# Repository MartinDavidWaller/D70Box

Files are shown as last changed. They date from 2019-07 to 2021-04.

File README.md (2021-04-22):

# D70Box

The D70Box project is documented in Practical Wireless, October 2019. If you require further information,
such as the associated circuit diagram or a PCB, then please contact me at martin@the-wallers.net.

*The project seems to have been rather popular with over 50 PCBs being shipped and, I assume 50 units being built. 
I think the reason for this is all down to the project keeping the look and feel of the original D70. It was an 
iconic look and people seem to be very nostalgic about it.*

# Erratum

Fonts! I originally thought that the label font was "microgramma d bold extended" but having listened to
Kermode and Mayo's Film Review podcast recently I think it might be "eurostile bold extended"! References
to this font include:

- https://typesetinthefuture.com/
- https://www.wired.co.uk/article/sci-fi-font-eurostile-bold-extended

A small design fault has been noticed. On the 74LS00 quad NAND gate pins 1,2,3,4,5,6, and 7 are all 
connected to ground. Pins 3 and 6 should have been left unconnected. This will not impact the overall 
functionality of the device but may result in slightly more current drain.

The suggested fix, for those who have soldered the 74LS00 directly onto the board and for those using 
a DIL socket, is to simply snip off pins 3 and 6.

V1.4 of the PCB is now available that will fix the problem without the need to snip off pins.

Some of the Arduino Pro Micro devices seem to be identifying themselves as "LilyPad Arduino USB" devices. If
the one you have claims to be one of these then under Tools > Boards select the "LilyPad Arduino USB" device 
and not "Arduino Leonardo".

Some Arduino Pro Micro devices also seem to be "Leonardo ETH" devices. A symtom of having the wrong Leonardo 
device selected seems to be odd data being displayed on the attached Bluetooth device.

A problem has been reported building the code with the Arduino 1.5.6-r2 IDE. This manifests with an
error saying "SwitchStates does not name a type". If you are facing this issue then please contact
me at martin@the-wallers.net and I'll provide the fix.

A problem has been reported where random 'Z' and random '9' characters were not being generated
as expected. This has now been fixed. Version number changed to V1.1.

## Required Hardware

Do shop around for these devices on ebay. I've noticed that the prices associated with the links below
have risen. You should be aiming to pay around £4 - £5 for the Arduino Pro Micro, or less if you buy from
China, and £2 - £3 for the Bluetooth module.

The circuit is based around the Arduino Pro Micro. This was purchased via ebay
from the URL https://www.ebay.co.uk/itm/1-2-5-10PCS-Pro-Micro-ATmega32U4-16MHz-5V-Replace-Pro-Mini-ATmega328-For-Arduino/283052304952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 but
it must be noted that other vendors supply this device too! Other vendors, especially if you are willing to wait, sell these much cheaper!

The HC-05 Bluetooth module was also purchased via ebay from the URL https://www.ebay.co.uk/itm/HM-10-BLE-Bluetooth-4-0-CC2540-CC2541-Serial-Wireless-Module-Arduino-F/123600639430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 
but it must be noted that other vendors supply this device too! The device is advertised as the HM-10 but it should be fine.

Other components include:

Resistors

- R1 150
- R5 2K
- R6 1K

Variable Resistors

- R2 10K Lin
- R3 10K Lin
- R4 22K Lin (Switched)

Semicondictors

- Q1 BFY51 or 2N3019
- U2 74LS00

Miscellaneous

- U3 Switch SPDT centre off
- S1 3.5 mm switch mono socket
- S2 3.5 mm switch mono socket
- SP1 8 Ohm speaker
- Header pins as required

DIL sockets for U2
Header sockets for Arduino and Bluetooth adapter

## Installing the Build Software

Start by installing the Arduino IDE. This can be found at:

https://www.arduino.cc/en/Main/Software

For the purpose of this build the Windows version Arduino 1.8.8 was used. 
All default installation options were accepted.

## Compiling the source code

- Download the associated ZIP file and uncompress it on your drive
- Open the Arduino IDE and then open the D70Box.ino project file in the Source\D70Box folder
- Navigate to Tools > Boards and select "Arduino Leonardo" (See Erratum above)
- Click the "Verify" button (Round circle with a tick mark in it - top left), if successful you will see something like 
"Sketch uses 14522 bytes (50%) of program storage space. Maximum is 28672 bytes.
Global variables use 741 bytes (28%) of dynamic memory, leaving 1819 bytes for local variables. Maximum is 2560 bytes."
though the number may not be exact.
- Make sure that the Arduino is plugged into your PC. Navigate to Tools > Port and make sure that the correct port is selected. See USB Issues below.
- Click the "Upload" button (Right pointing arrow - top left) to up load the software.
- The device should now be programmed correctly.

## USB Issues

Some users have reported issues connecting the Arduino to the PC USB 3.0 sockets.
It seems that the Arduino Pro-Micro is happier connected to a USB 2.0 sockets for programming.
More information can be found here: https://learn.sparkfun.com/tutorials/pro-micro--fio-v3-hookup-guide/all

## PCB Revisions

- V1.4 - September 29th, 2019 - Fixed the issue with 7400 outputs pins 3 and 6 being tied low.
- V1.3 - June 4th, 2019 - Fixed legend for T1, should read BFY51 and not BFY71.
- V1.2 - May 24th, 2019 - Added BlueTooth support.
- V1.1 - ?
- V1.0 - April 5th, 2019 - Initial board design.

## Knobs

I have managed to re-create a realistic looking D70 knob. 
The knob is designed to provide a friction fit to a knurled 6mm diameter shaft - split or otherwise.
The 3D design has been created using
OpenSCAD - see https://www.openscad.org/ 

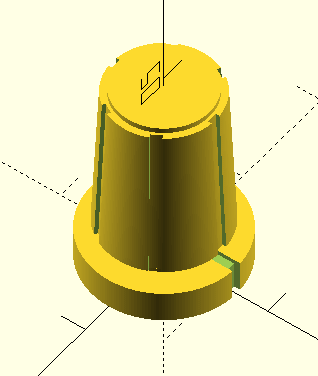
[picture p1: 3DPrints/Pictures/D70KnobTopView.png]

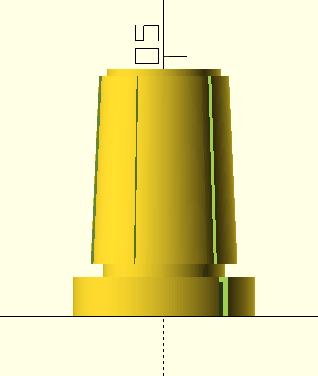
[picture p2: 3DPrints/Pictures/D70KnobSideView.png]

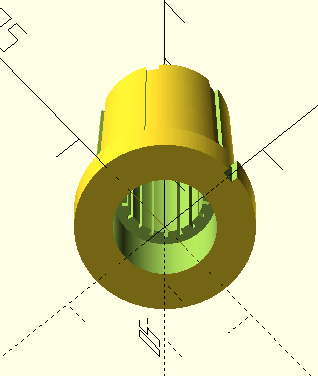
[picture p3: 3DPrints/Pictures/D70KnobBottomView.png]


The OpenSCAD source file and associated STL file can be found in the 3DPrints folder.

## Notes

The Delay and Speed setting may seem wrong relative to the knob position. The best way to check this is to use the BlueTooth
interface and look for the Delay and Speed setting. Adjust the two control until the values displayed match values on the
legend. Then adjust the knobs so that the indicator is as close as possible to the legend value. The attained proximity will 
depend on the potentiometer shaft type, smooth or knurled / serrated etc.

The BFY51 transistor can be substituted with a 2N3019. See https://ham.stackexchange.com/questions/8990/can-anyone-please-suggest-a-substitute-for-the-bfy51-transistor/9031

The Bluetooth card may prompt for a PIN, this is likely to be either 1234, or 0000.

## User Builds

David, G4DMP, has sent in a picture of his completed build.

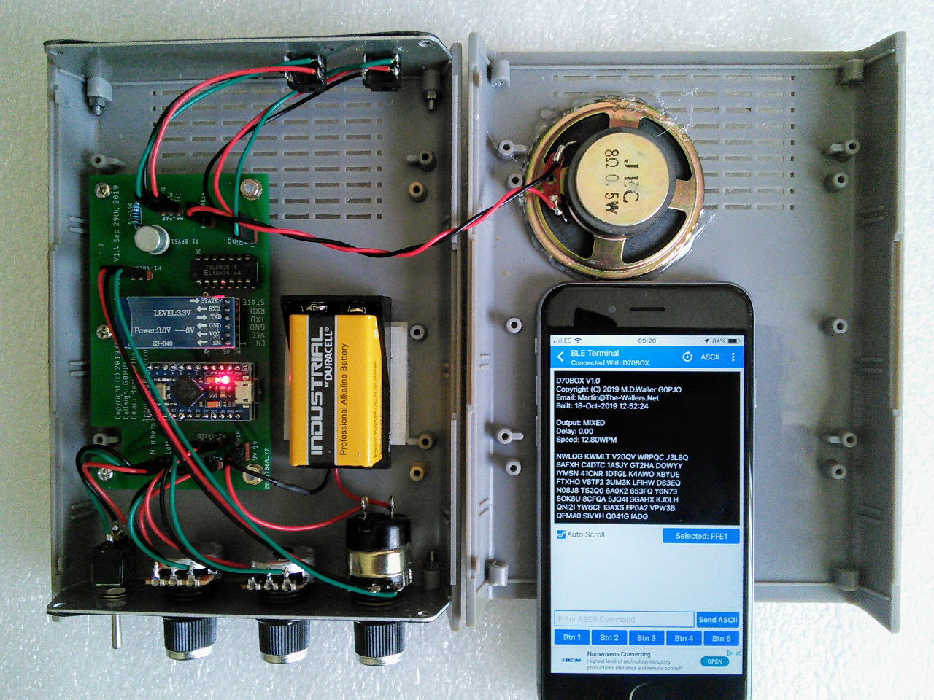
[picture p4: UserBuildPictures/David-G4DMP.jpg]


David, G4EDR, has also sent in a picture of his completed build.

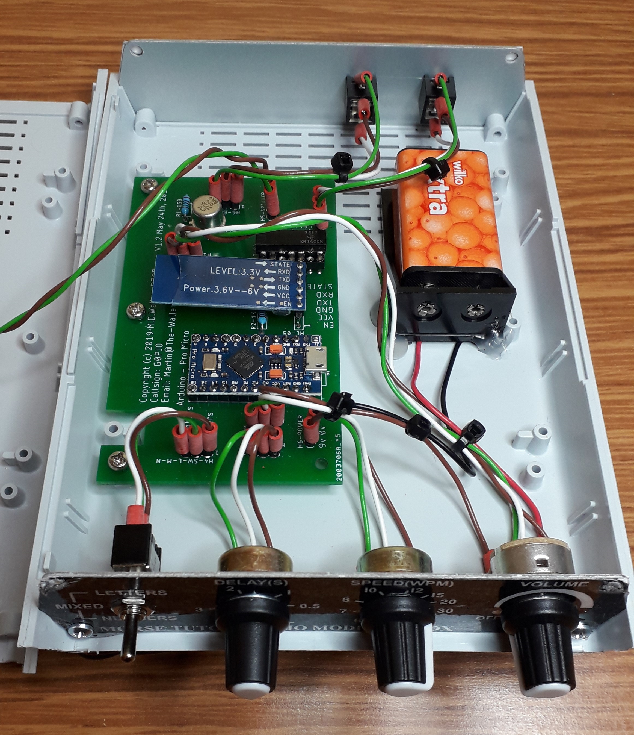
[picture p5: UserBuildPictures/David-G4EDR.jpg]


Stephen, GI7ISX, has also sent in a couple of pictures of his completed build.

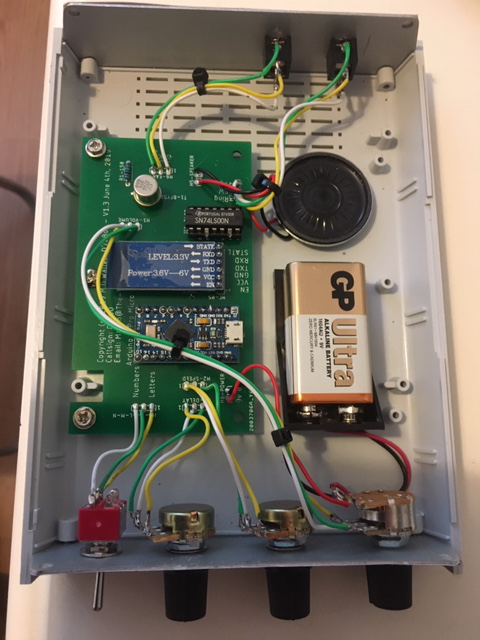
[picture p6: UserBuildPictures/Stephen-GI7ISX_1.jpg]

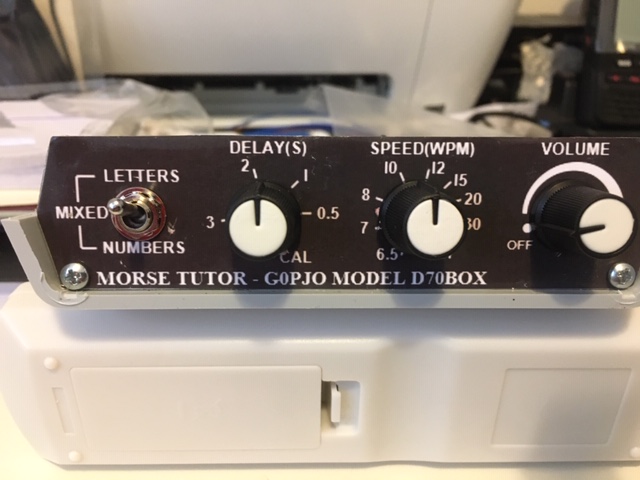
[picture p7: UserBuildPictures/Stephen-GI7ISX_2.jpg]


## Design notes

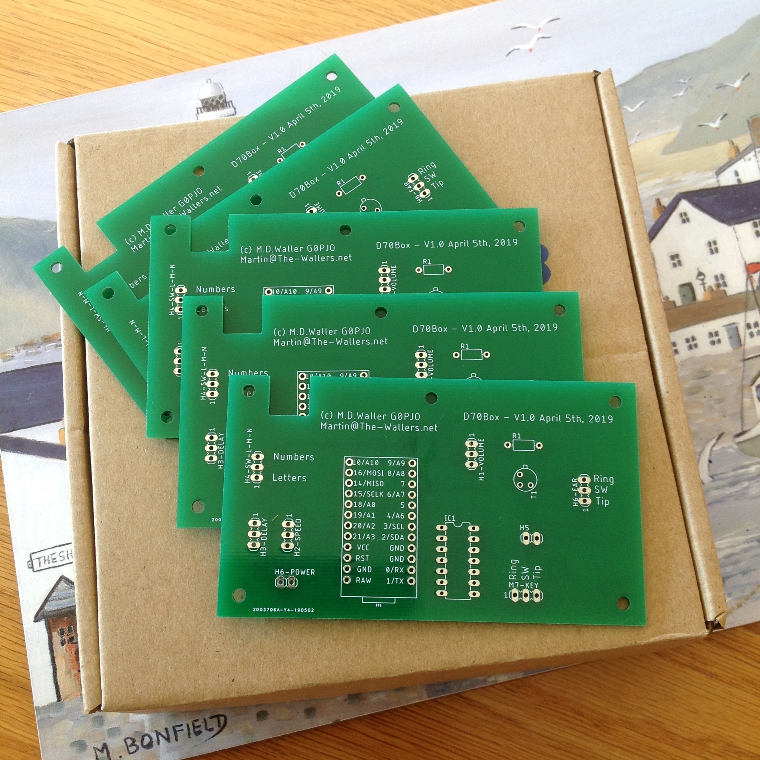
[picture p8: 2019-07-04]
Pictures/PCB_V1_0.JPG

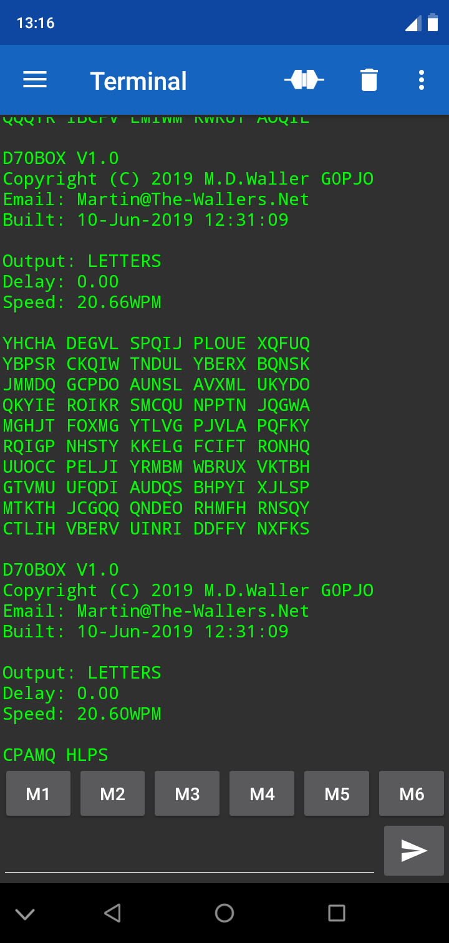
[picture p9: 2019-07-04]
Pictures/Screenshot_20190610-131609.png

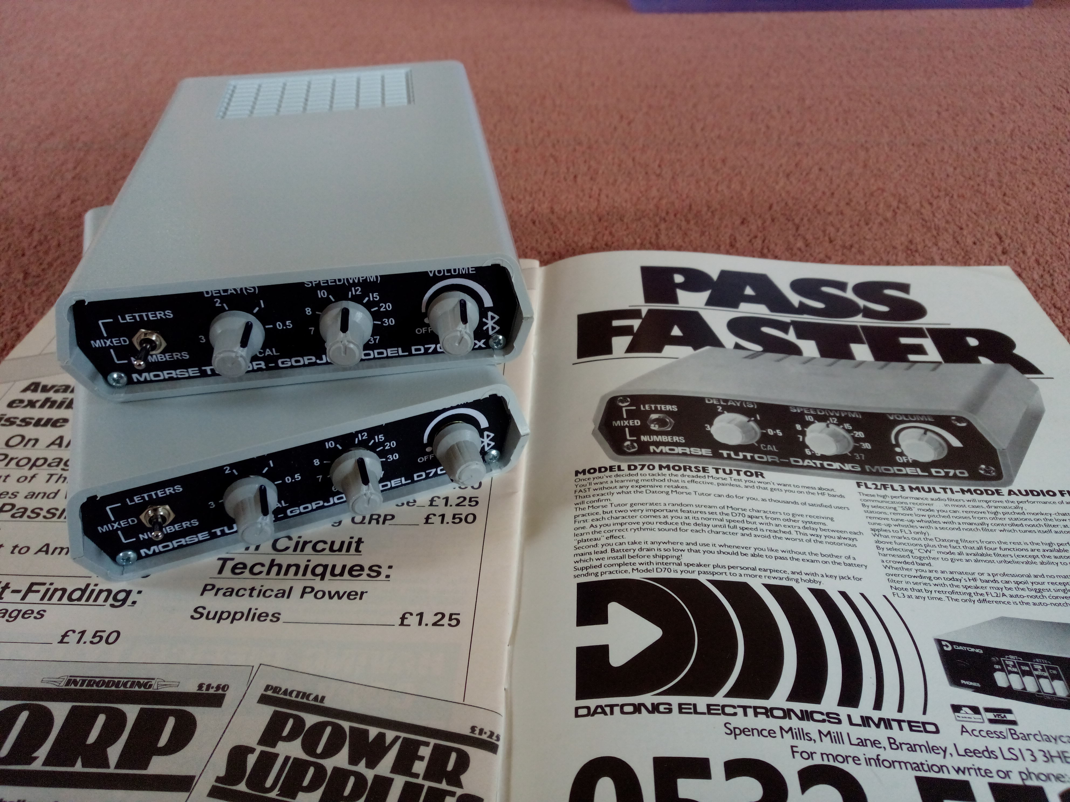
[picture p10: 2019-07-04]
Pictures/IMG_20190610_142815_1CS.jpg

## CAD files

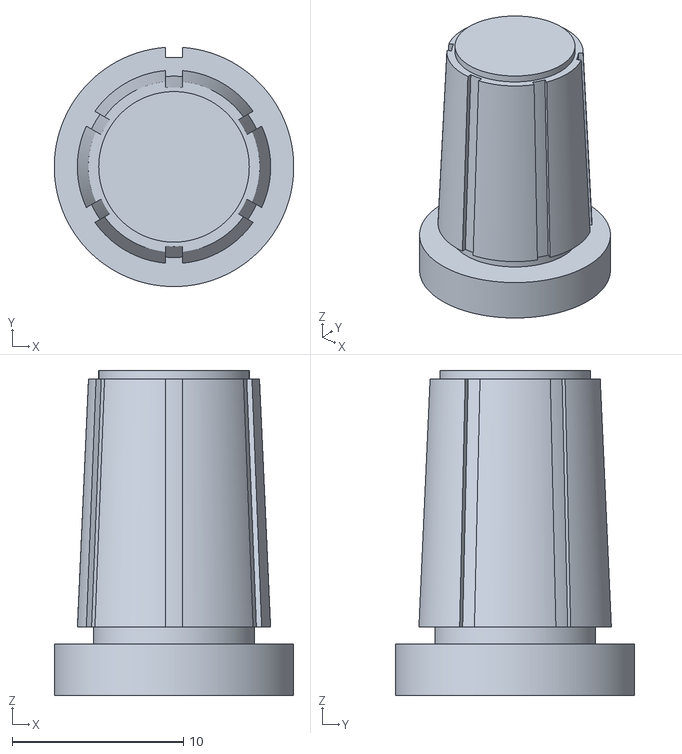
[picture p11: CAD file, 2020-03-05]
3DPrints/D70Knob.stl
14.0 x 14.0 x 19.0

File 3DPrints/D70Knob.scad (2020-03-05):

//
//  D70 Knob
//
//  Author:         M.D.Waller
//  Date:           February 27th, 2020
//
//  Date:           Modified By:    What:
//  =====           ============    =====
//
//  ?               ?               ?
//

cylinderResolution = 200;

module mainKnob()
{
    union()
    {
        // Build the top cap
        
        translate([0,0,18.5]) cylinder(r=8.8 / 2, h=0.5, $fn=cylinderResolution);
    
        // Build the main body of the knob
        
        translate([0,0,4]) cylinder(r1=(11.3 - 0.7) / 2, r2= (10 - 0.7) / 2, h=18.5 - 1 - 3, $fn=cylinderResolution);
    
        // Build the skirt recess
        
        translate([0,0,3]) cylinder(r=9.4 / 2, h=1, $fn=cylinderResolution);
    
        // Build the skirt
        
        translate([0,0,0]) cylinder(r=14 / 2, h=3, $fn=cylinderResolution);    
    }
}

module grip()
{
    difference()
    {
        translate([0,0,4]) cylinder(r1=11.3 / 2, r2= 10 / 2, h=18.5 - 1 - 3, $fn=cylinderResolution);
        
        for(i = [0 : 5]) 
        {
            rotate([0,0,i * 60]) translate([-0.5,0,0]) cube([1,10,20]);
        }
    }
}

module potShaft()
{
    union()
    {
        for(i = [0 : 19]) 
        {
            rotate([0,0,i * 20]) translate([0,-0.25 / 2,5]) cube([3.4,0.25,11]);
        }
        
        translate([0,0,5]) cylinder(r= 2.95, h=11, $fn=cylinderResolution);  
        
        translate([0,0,-1]) cylinder(r=4, h=6.3, $fn=cylinderResolution);
    }
}
 
// Build the Knob

difference()
{
    // Stick the grip to the main knob
    
    union()
    {
        grip();
        mainKnob();
    }
    
    // Remove the skirt marker
    
    translate([-0.5,6.4,-0.5]) cube([1,10,4]);
    translate([-0.5,6.4,2.6]) cube([1,10,3]);
    translate([-0.5,4.7,2.6]) cube([1,10,1]);

    // Remove the pot shaft
    
    potShaft();
}

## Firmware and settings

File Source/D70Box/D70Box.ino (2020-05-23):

/* ====================================================================
 * Copyright (c) 2019 Martin D. Waller - G0PJO.  All rights reserved.
 *
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
 * 1. Redistributions of source code must retain the above copyright
 *    notice, this list of conditions and the following disclaimer. 
 *
 * 2. Redistributions in binary form must reproduce the above copyright
 *    notice, this list of conditions and the following disclaimer in
 *    the documentation and/or other materials provided with the
 *    distribution.
 *
 * 3. All advertising materials mentioning features or use of this
 *    software must display the following acknowledgment:
 *    "This product includes software developed by Martin D. Waller - G0PJO"
 *
 * 4. The names "D70Box" must not be used to endorse or promote 
 *    products derived from this software without prior written permission.
 *
 * 5. Products derived from this software may not be called "D70Box"
 *    nor may "D70Box" appear in their names without prior written
 *    permission of Martin D. Waller.
 *
 * 6. Redistributions of any form whatsoever must retain the following
 *    acknowledgment:
 *
 *    "This product includes software developed by Martin D. Waller - G0PJO"
 *
 * THIS SOFTWARE IS PROVIDED BY Martin D. Waller ``AS IS'' AND ANY
 * EXPRESSED OR IMPLIED WARRANTIES, INCLUDING, BUT NOT LIMITED TO, THE
 * IMPLIED WARRANTIES OF MERCHANTABILITY AND FITNESS FOR A PARTICULAR
 * PURPOSE ARE DISCLAIMED.  IN NO EVENT SHALL THE OpenSSL PROJECT OR
 * ITS CONTRIBUTORS BE LIABLE FOR ANY DIRECT, INDIRECT, INCIDENTAL,
 * SPECIAL, EXEMPLARY, OR CONSEQUENTIAL DAMAGES (INCLUDING, BUT
 * NOT LIMITED TO, PROCUREMENT OF SUBSTITUTE GOODS OR SERVICES;
 * LOSS OF USE, DATA, OR PROFITS; OR BUSINESS INTERRUPTION)
 * HOWEVER CAUSED AND ON ANY THEORY OF LIABILITY, WHETHER IN CONTRACT,
 * STRICT LIABILITY, OR TORT (INCLUDING NEGLIGENCE OR OTHERWISE)
 * ARISING IN ANY WAY OUT OF THE USE OF THIS SOFTWARE, EVEN IF ADVISED
 * OF THE POSSIBILITY OF SUCH DAMAGE.
 * ====================================================================
 */

//    Created:	  M.D.Waller		May 16th, 2019
//                a) Initial coding.
//
//    Modified:   M.D.Waller    May 23rd, 2019
//                a) Add support for Bluetooth.
//
//    Modified:   M.D.Waller    May 23rd, 2020
//                a) Bug fix, it was not producing 'Z' or
//                '9' in the random list!
//
// TODO
//
// -
//
// The DATONG D70 Morse Tutor first appeared in 1980, almost 40 years
// ago. It was described by DATONG as:
//
// "The revolutionary new way to practice Morse Code reception. An 
// unlimited supply of precision Morse at the turn of a switch, plus 
// built-in oscillator for sending practice."
//
// They were not cheap at the time but sold well and even today can 
// demand £30+ on eBay.
//
// DATONG
//
// Font: MicrogrammeD-BoldExte
//
// How long is standard dit?
//
// The relationship between Dits and Dahs is well documented.
//
// 1 Dah = 3 Dits
// The gap between Dits and Dahs is the duration of 1 Dit
// The gap between letters is the duration of 3 Dits
// The gap between words is the duration of 7 Dits

// Standard for CW speed is based around the word PARIS. If you sum up the
// duration of all the letters, associated gaps, and trailing word gap then
// it would be equivalent to 50 Dits.
//
// If you were to send the word PARIS 5 times then that would be equivalant
// to 250 Dits. Assuming a sending speed of 5 Word Per Minutes then:
//
// 1 Minutes = 60 Seconds
// 60 Seconds / 250 Dits = 0.24 Seconds (250ms) Per Dit
//
// The Delay and Speed potentiometers are linear but the legend on
// the D70 is anything but! To replicate the device as closely as
// possible the actual values are generated via polynomials fitted
// to the data taken from the actual value returned from the A to D
// reading and the legend value. These polynomials were generated
// using a tool called CurveExpert from https://www.curveexpert.net.
//
// Bluetooth
//
// There are many Bluetooth devices available and they are very confusing!
//
// Command Set
//
// HC-05
//
//  AT+BAUD4      - Set the baud rate to 9600
//  AT+NAMED70    - Set the device name to D70
//  AT+REST       - Reset the device

#include <Arduino.h>
#include "Entropy.h"

// Debug manifests

//define DEBUG_DISPLAY_POT_DATA
//define DEBUG_LETTERS_MIXED_NUMBERS
//define DEBUG_DIT_LENGTH_MS

// Bluetooth Manifests

#define BUILD_WITH_BLUETOOTH 1
#define BLUETOOTH_BAUDRATE 9600

// Version manifests

#define PROGRAM_NAME "D70BOX"
#define PROGRAM_VERSION_MAJOR 1
#define PROGRAM_VERSION_MINOR 1

// Hardware related manifests

#define SPEAKER_PIN 5       // Pin 5
#define SPEAKER_ON_PIN 7    // Pin 7
#define LETTERS_PIN 8       // Pin 8
#define NUMBERS_PIN 9       // Pin 9
#define SPEED_PIN 18        // Pin A0
#define DELAY_PIN 19        // Pin A1

#define GROUPS_PER_LINE 5
#define GROUPS_BETWEEN_VERSION 50

#define ANALOGUE_HIGH 1023

// D70 related manifests

#define D70_GROUP_LENGTH 5
#define D70_TONE_FREQUENCY 630 

// This enumeration is used to indicate the state
// of the Letters | Mixed | Numbers switch

enum SwitchStates {
  LETTERS,
  MIXED,
  NUMBERS        
};

// Morse related manifests

#define DITPDAH 3
#define DITBLET 3
#define DITBWRD 7

// The following manifests contains all the Morse characters that we
// will be sending. The top 3 bits of each byte contains the length
// of Morse character - the number of dits and dahs. The lower
// 5 bits contain the code, a 1 represents a dah and a 0 represents
// a dit.

#define MORSE_CODE_A 0b01001000 // A ._      5 dits
#define MORSE_CODE_B 0b10010000 // B _...    9 dits
#define MORSE_CODE_C 0b10010100 // C _._.   11 dits
#define MORSE_CODE_D 0b01110000 // D _..     7 dits
#define MORSE_CODE_E 0b00100000 // E .       1 dits
#define MORSE_CODE_F 0b10000100 // F .._.    9 dits
#define MORSE_CODE_G 0b01111000 // G __.     9 dits
#define MORSE_CODE_H 0b10000000 // H ....    7 dits
#define MORSE_CODE_I 0b01000000 // I ..      3 dits
#define MORSE_CODE_J 0b10001110 // J .___   13 dits
#define MORSE_CODE_K 0b01110100 // K _._     9 dits
#define MORSE_CODE_L 0b10001000 // L ._..    9 dits
#define MORSE_CODE_M 0b01011000 // M __      7 dits
#define MORSE_CODE_N 0b01010000 // N _.      5 dits
#define MORSE_CODE_O 0b01111100 // O ___    11 dits
#define MORSE_CODE_P 0b10001100 // P .__.   11 dits
#define MORSE_CODE_Q 0b10011010 // Q __._   13 dits
#define MORSE_CODE_R 0b01101000 // R ._.     7 dits
#define MORSE_CODE_S 0b01100000 // S ...     5 dits
#define MORSE_CODE_T 0b00110000 // T _       3 dits
#define MORSE_CODE_U 0b01100100 // U .._     7 dits
#define MORSE_CODE_V 0b10000010 // V ..._    9 dits
#define MORSE_CODE_W 0b01101100 // W .__     9 dits
#define MORSE_CODE_X 0b10010010 // X _.._   11 dits
#define MORSE_CODE_Y 0b10010110 // Y _.__   13 dits
#define MORSE_CODE_Z 0b10011000 // Z __..   11 dits
#define MORSE_CODE_0 0b10111111 // 0 _____  19 dits
#define MORSE_CODE_1 0b10101111 // 1 .____  17 dits
#define MORSE_CODE_2 0b10100111 // 2 ..___  15 dits
#define MORSE_CODE_3 0b10100011 // 3 ...__  13 dits
#define MORSE_CODE_4 0b10100001 // 4 ...._  11 dits
#define MORSE_CODE_5 0b10100000 // 5 .....   9 dits
#define MORSE_CODE_6 0b10110000 // 6 _....  11 dits
#define MORSE_CODE_7 0b10111000 // 7 __...  13 dits
#define MORSE_CODE_8 0b10111100 // 8 ___..  15 dits
#define MORSE_CODE_9 0b10111110 // 9 ____.  17 dits

// The following array contains all the characters that we may need.

char morseCodeAscii[] = {
    'A', // ._    
    'B', // _...  
    'C', // _._.  
    'D', // _..   
    'E', // .     
    'F', // .._.  
    'G', // __.   
    'H', // ....  
    'I', // ..    
    'J', // .___  
    'K', // _._   
    'L', // ._..  
    'M', // __    
    'N', // _.    
    'O', // ___   
    'P', // .__.  
    'Q', // __._  
    'R', // ._.   
    'S', // ...   
    'T', // _     
    'U', // .._   
    'V', // ..._  
    'W', // .__   
    'X', // _.._  
    'Y', // _.__  
    'Z', // __..  
    '0', // _____ 
    '1', // .____ 
    '2', // ..___ 
    '3', // ...__ 
    '4', // ...._ 
    '5', // ..... 
    '6', // _.... 
    '7', // __... 
    '8', // ___.. 
    '9'  // ____. 
};

byte morseCodeCharacters[] = {
    MORSE_CODE_A, // [ 0] A ._    
    MORSE_CODE_B, // [ 1] B _...  
    MORSE_CODE_C, // [ 2] C _._.  
    MORSE_CODE_D, // [ 3] D _..   
    MORSE_CODE_E, // [ 4] E .     
    MORSE_CODE_F, // [ 5] F .._.  
    MORSE_CODE_G, // [ 6] G __.   
    MORSE_CODE_H, // [ 7] H ....  
    MORSE_CODE_I, // [ 8] I ..    
    MORSE_CODE_J, // [ 9] J .___  
    MORSE_CODE_K, // [10] K _._   
    MORSE_CODE_L, // [11] L ._..  
    MORSE_CODE_M, // [12] M __    
    MORSE_CODE_N, // [13] N _.    
    MORSE_CODE_O, // [14] O ___   
    MORSE_CODE_P, // [15] P .__.  
    MORSE_CODE_Q, // [16] Q __._  
    MORSE_CODE_R, // [17] R ._.   
    MORSE_CODE_S, // [18] S ...   
    MORSE_CODE_T, // [19] T _     
    MORSE_CODE_U, // [20] U .._   
    MORSE_CODE_V, // [21] V ..._  
    MORSE_CODE_W, // [22] W .__   
    MORSE_CODE_X, // [23] X _.._  
    MORSE_CODE_Y, // [24] Y _.__  
    MORSE_CODE_Z, // [25] Z __..  
    MORSE_CODE_0, // [26] 0 _____ 
    MORSE_CODE_1, // [27] 1 .____ 
    MORSE_CODE_2, // [28] 2 ..___ 
    MORSE_CODE_3, // [29] 3 ...__ 
    MORSE_CODE_4, // [30] 4 ...._ 
    MORSE_CODE_5, // [31] 5 ..... 
    MORSE_CODE_6, // [32] 6 _.... 
    MORSE_CODE_7, // [33] 7 __... 
    MORSE_CODE_8, // [34] 8 ___.. 
    MORSE_CODE_9  // [35] 9 ____. 
};

// PARIS
//
//	0b10001100, // [15] P .__.   11 dits
//	0b01001000, // [ 0] A ._      5 dits
//	0b01101000, // [17] R ._.     7 dits
//	0b01000000, // [ 8] I ..      3 dits
//	0b01100000, // [18] S ...     5 dits
//
// Total bits = 11 + 3 +
//               5 + 3 +
//               7 + 3 +
//               3 + 3 +
//               5 + 7
//            = 50
//
// So PARIS repeated 5 times would be 5 * 50 = 250.
    
// The following manifests are used to extract the length
// and associated code bits.

#define LENGTH_MASK 0b11100000
#define LENGTH_MASK_SHIFT 5
#define LENGTH_OF_CODE(X) (((X) & LENGTH_MASK) >> LENGTH_MASK_SHIFT)
#define CODE_MASK 0b00011111

/*
 * This method is called to evaluate a polynomial. It is passed
 * the X value, the degree of the polynomial, and an array of
 * coefficients. The coefficient array starts with the constant
 * followed by the X, X^2, X^3, ... coefficients.
 */
float evalPolynomial(float x, int degree, float *coefficients)
{
  // Start off with the constant
  
  float retVal = *coefficients++;

  // Set V to the X value
  
  float v = x;
  for(int i = 0; i < degree; i++)
  {
    // Add in the coefficient times the value
    
    retVal += *coefficients++ * v;

    // Turn X into X^2, etc.
    v = v * x;
  }

  // Return the result
  
  return retVal;
}

/*
 * This method is called to read the delay control. It will return
 * the required number of seconds delay.
 */
float readDelay()
{
  int potValue = analogRead(DELAY_PIN);

  // Convert value to a speed in Delay in seconds
  
  float coefficients[] = {3.486453, -3.50352e-03, 4.90175e-08};

  float delaySeconds = evalPolynomial(potValue,2,&coefficients[0]);
  if (delaySeconds < 0)
    delaySeconds = 0;

#ifdef DEBUG_DISPLAY_POT_DATA
  Serial.println("readDelay()");

  Serial.print("potValue = ");
  Serial.println(potValue);
    
  Serial.print("Delay Seconds = ");
  Serial.println(delaySeconds);
#endif
        
  return delaySeconds;
}

/*
 * This method is called to read the speed control and return the
 * currently selected words per minute.
 */
float readSpeed()
{
  // Read the potentiometer value
  
  int potValue = analogRead(SPEED_PIN);

  // Convert value to a speed in WPM

  float coefficients[] = {6.58477440249751, 8.026122191756975e-03, -2.064085150344916e-5, 4.181177226081519e-8};

  float speedWPM = evalPolynomial(potValue,3,&coefficients[0]);

#ifdef DEBUG_DISPLAY_POT_DATA
  Serial.println("readSpeed()");

  Serial.print("potValue = ");
  Serial.println(potValue);
    
  Serial.print("Speed WPM = ");
  Serial.println(speedWPM);
#endif
  
  return (speedWPM);
}

/*
 * This method is called to convert a number of Words Per Minute
 * to the number of milliseconds that represents ond dit at that
 * given speed.
 */
float ditLengthMS(float wordsPerMinute)
{
  // Calculate the dit length in MS for the given speed

  float retVal = (60.0 / (wordsPerMinute * 50.0)) * 1000.0;
  
#ifdef DEBUG_DIT_LENGTH_MS
  Serial.println("ditLengthMS()");
  Serial.print("Dit length = ");
  Serial.println(retVal);
#endif

  return retVal;
}

/*
 * This method is called to send out the given Morse code
 * character using the given number of milliseconds for each
 * dit.
 */
void sendCharacter(byte character, int ditLengthMS)
{
  byte characterLength = LENGTH_OF_CODE(character);

  byte codeMask = (CODE_MASK + 1) >> 1;
  for(int i = 0; i < characterLength; i++)
  {
    int toneOnDuration = ditLengthMS;
    if ((character & codeMask) > 0)
    {
      // We're sending a Dah, update the tone on duration
        
      toneOnDuration *= DITPDAH;
    }

    // Turn the tone on, wait, turn it off.

    // Send the Dit or Dah
    
    digitalWrite(SPEAKER_ON_PIN,HIGH);
    delay(toneOnDuration);
    digitalWrite(SPEAKER_ON_PIN,LOW);

    // Delay for the inter dit/dah gap but only if
    // we need it

    if (i != characterLength - 1)
      delay(ditLengthMS);      

    // Move the code mask along one
      
    codeMask >>= 1;
  }
}

/*
 * This method is called to read the state of the Letters |
 * Mixed | Numbers switch. It will return the associated
 * enumeration value.
 */
SwitchStates readLettersMixedNumbers()
{
  SwitchStates retVal = MIXED;
  
  if (LOW == digitalRead(LETTERS_PIN))
    retVal = LETTERS;
  else if (LOW == digitalRead(NUMBERS_PIN))
    retVal = NUMBERS;

#ifdef DEBUG_LETTERS_MIXED_NUMBERS
  Serial.println("readLettersMixedNumbers()");
  Serial.print("retVal = ");
  switch(retVal) 
  {
    case LETTERS:
      Serial.println("LETTERS");
      break;
    case MIXED:
      Serial.println("MIXED");
      break;
    case NUMBERS:
      Serial.println("NUMBERS");
      break;
    default:
      Serial.println("?");
  }
#endif
  
  return retVal;
}
  
void setup() {

  // Setup the serial link for debugging
  
  Serial.begin(9600);

#ifdef BUILD_WITH_BLUETOOTH   
  Serial1.begin(BLUETOOTH_BAUDRATE);
#endif
  
  // put your setup code here, to run once:

  Entropy.initialize();

  randomSeed(Entropy.random());

  // Initialize pins

  pinMode(LETTERS_PIN,INPUT_PULLUP);
  pinMode(NUMBERS_PIN,INPUT_PULLUP);
  pinMode(SPEED_PIN,INPUT);
  pinMode(DELAY_PIN,INPUT);
  pinMode(SPEAKER_PIN,OUTPUT);
  pinMode(SPEAKER_ON_PIN,OUTPUT);

  // Turn off the SPEAK_ON_PIN

  digitalWrite(SPEAKER_ON_PIN,LOW);
  
  // Turn on the tone
      
  tone(SPEAKER_PIN,D70_TONE_FREQUENCY);   

  if (readSpeed() > 30) 
  {
    // Announce the version details

    // D70BOX VERSION V

    byte _space = -1;

    // Build the text to send
    
    int textCode[] = {
      MORSE_CODE_D,
      MORSE_CODE_7,
      MORSE_CODE_0,
      MORSE_CODE_B,
      MORSE_CODE_O,
      MORSE_CODE_X,
      _space,
      MORSE_CODE_V
    };

    // Get the dit length for 12WPM
    float ditLength12WPM = ditLengthMS(12);

    // Send the text
    
    for(int i = 0; i < 8; i++)
    {
      int characterToSend = textCode[i];

      if (_space == characterToSend)
      {
        delay(DITBWRD * ditLength12WPM);
      }
      else
      {
        sendCharacter((byte)characterToSend,ditLength12WPM);
        delay(DITBLET * ditLength12WPM);
      }
    }

    // Add in the version number
    
    sendCharacter(morseCodeCharacters[26 + PROGRAM_VERSION_MAJOR],ditLength12WPM);
    delay(DITBLET * ditLength12WPM);
    sendCharacter(morseCodeCharacters[26 + PROGRAM_VERSION_MINOR],ditLength12WPM);

    // Final delay
    
    delay(DITBWRD * ditLength12WPM * 2);
  }

#ifdef BUILD_WITH_BLUETOOTH 

    // Wait for the serial device
    
    while(!Serial1) { ; }
    
    // Set the name of the device and read any reply
      
    Serial1.write("AT+NAME");
    Serial1.write(PROGRAM_NAME);
    Serial1.write("\r\n");
    delay(500);
    while(Serial1.available())
      Serial.write(Serial1.read());  

    // Reset the device. This should allow contacts to
    // the name given above.

    Serial1.write("AT+RESET\r\n");
    delay(500);
    while(Serial1.available())
      Serial.write(Serial1.read());     
#endif 
}

void buildDateTime(char *buffer) { 
  
    char month[4];
    int day;
    int year;
    
    // Pull the date apart
    
    sscanf(__DATE__, "%s %d %d", month, &day, &year);

    // Reformat it
    
    sprintf(buffer, "%02d-%s-%04d %s",day,month,year,__TIME__);
}

/*
 * This is the main loop. Here we simply need to send out a group of 
 * random characters with the correct spacing and the correct word
 * spacing at the end. The Arduino base loop will take care of the
 * rest.
 */
 
int groupNumber = 0;
int totalGroups = 0;

void loop() {

  // We need to produce a group of random characters but we need to look
  // out for the operating mode changing.
  
  int currentDitLengthMS;
  
  // In the loop we are simply going to send out a well formed group of five characters
  // depending on the character groups selected, the delay, and the speed.

#ifdef BUILD_WITH_BLUETOOTH 

  if((totalGroups % GROUPS_BETWEEN_VERSION) == 0)
  {
    char lineBuffer[30];
    
    Serial1.println();
    sprintf(lineBuffer,"%s V%d.%d",PROGRAM_NAME,PROGRAM_VERSION_MAJOR,PROGRAM_VERSION_MINOR);
    Serial1.println(lineBuffer);
    Serial1.println("Copyright (C) 2019 M.D.Waller G0PJO");
    Serial1.println("Email: Martin@The-Wallers.Net");
        
    buildDateTime(lineBuffer);
    
    Serial1.print("Built: ");
    Serial1.println(lineBuffer);

    Serial1.println();

    Serial1.print("Output: ");
    SwitchStates lettersMixedNumbers = readLettersMixedNumbers();
    switch(lettersMixedNumbers)
    {
      case LETTERS:
        Serial1.println("LETTERS");
        break;
      case MIXED:
        Serial1.println("MIXED");
        break;
      case NUMBERS:
        Serial1.println("NUMBERS");
        break;
    }

    Serial1.print("Delay: ");
    Serial1.println(readDelay());

    Serial1.print("Speed: ");
    Serial1.print(readSpeed());
    Serial1.println("WPM");

    Serial1.println();
  }
  
#endif

  totalGroups++;
  
  for(int i = 0; i < D70_GROUP_LENGTH; i++)
  {
    // Get the Letters/Mixed/Numbers state

    SwitchStates lettersMixedNumbers = readLettersMixedNumbers();

    // Sort out the random character range

    int minCharacter = 0;
    int maxCharacter = 36;

    switch(lettersMixedNumbers)
    {
      case LETTERS:
        maxCharacter = 26;
        break;
      case NUMBERS:
        minCharacter = 26;
        break;
    }
    
    // Pull out the random character

    int randomIndex = Entropy.random(minCharacter, maxCharacter);
    char asciiCharracterToSend = morseCodeAscii[randomIndex];
    byte characterToSend = morseCodeCharacters[randomIndex];

    // Display the character

#ifdef BUILD_WITH_BLUETOOTH     
    Serial1.print(char(asciiCharracterToSend));
#endif
    
    // Read the current speed value
    
    float currentSpeed = readSpeed();

    // Workout the associated dit length in milliseconds
    
    currentDitLengthMS = (int)ditLengthMS(currentSpeed);
    
    // Send out the character with the given dit length
    
    sendCharacter(characterToSend,currentDitLengthMS);

    // Put in the inter letter gap if we are not at the end
    // of the group.

    if (i != (D70_GROUP_LENGTH - 1))
      delay(DITBLET * currentDitLengthMS);

    // Add any extra delay that might be required

    delay(readDelay() * 1000);
  }

#ifdef BUILD_WITH_BLUETOOTH 

  // Update the group number and space / line break as required

  groupNumber++;
  if (groupNumber > GROUPS_PER_LINE - 1) 
  {
    Serial1.println();
    groupNumber = 0;
  }
  else
    Serial1.print(" ");
    
#endif    

  // Put in the word break after ths group

  delay(DITBWRD * currentDitLengthMS);

  // Add any extra delay that might be required

  delay(readDelay() * 1000);  
}

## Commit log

2019-07-05 Documentation update
    Added information about PCB revisions.
2019-07-18 Update README.md
    Added comments about Arduino price.
2019-08-05 Create D70BoxBT - V1_3.brd
    Added PCB board.
    [D70BoxBT - V1_3.brd]
2019-09-23 Compiler problem with Arduino 1.5.6-r2 IDE
    See ReadMe
2019-09-30 Added new PCB
    See V1.4
    [D70BoxBT - V1_4.brd]
2019-09-30 Forgot the PCB revision!
    See comment
2019-11-05 Added PIN information
    See above.
2020-03-05 Added 3D knob
    Added code and pictures for the 3D Knob.
    [D70Knob.scad, D70Knob.stl]
2020-05-23 Bug fix
    See README.md
    [D70Box.ino]
